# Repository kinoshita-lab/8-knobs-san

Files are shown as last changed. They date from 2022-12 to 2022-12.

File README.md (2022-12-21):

# 8-knobs-san kit

[Document in Japanese](README_ja.md)
## PCB board with 8 Potentiometers

8-knobs-san is a handy PCB with 8 potentiometers and analog multiplexer.
You can connect another 8-knobs-san PCB with same GPIOs, by switching /Enable pin with builtin inverter.

## Kit contents

- Pre-assembled circuit board
- 1x7 pin socket

## How to assemble

Solder the included 1x7 pin socket into the following place below:
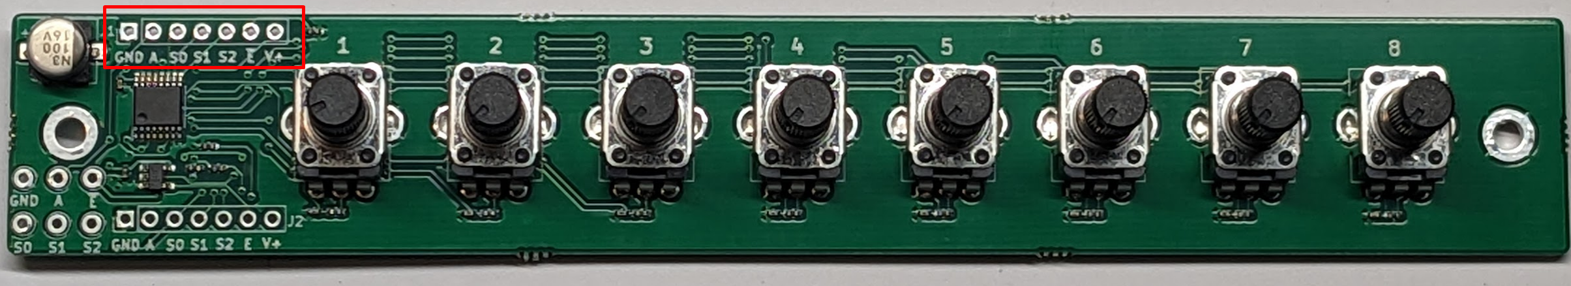
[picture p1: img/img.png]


## Sample program

Please refer to the software/exapmle <https://github.com/kinoshita-lab/8-knobs-san/tree/main/software/example>

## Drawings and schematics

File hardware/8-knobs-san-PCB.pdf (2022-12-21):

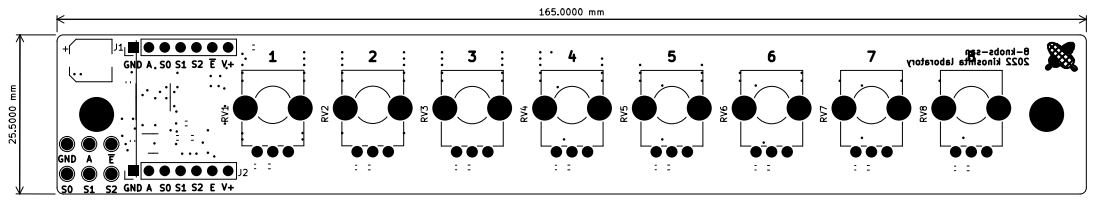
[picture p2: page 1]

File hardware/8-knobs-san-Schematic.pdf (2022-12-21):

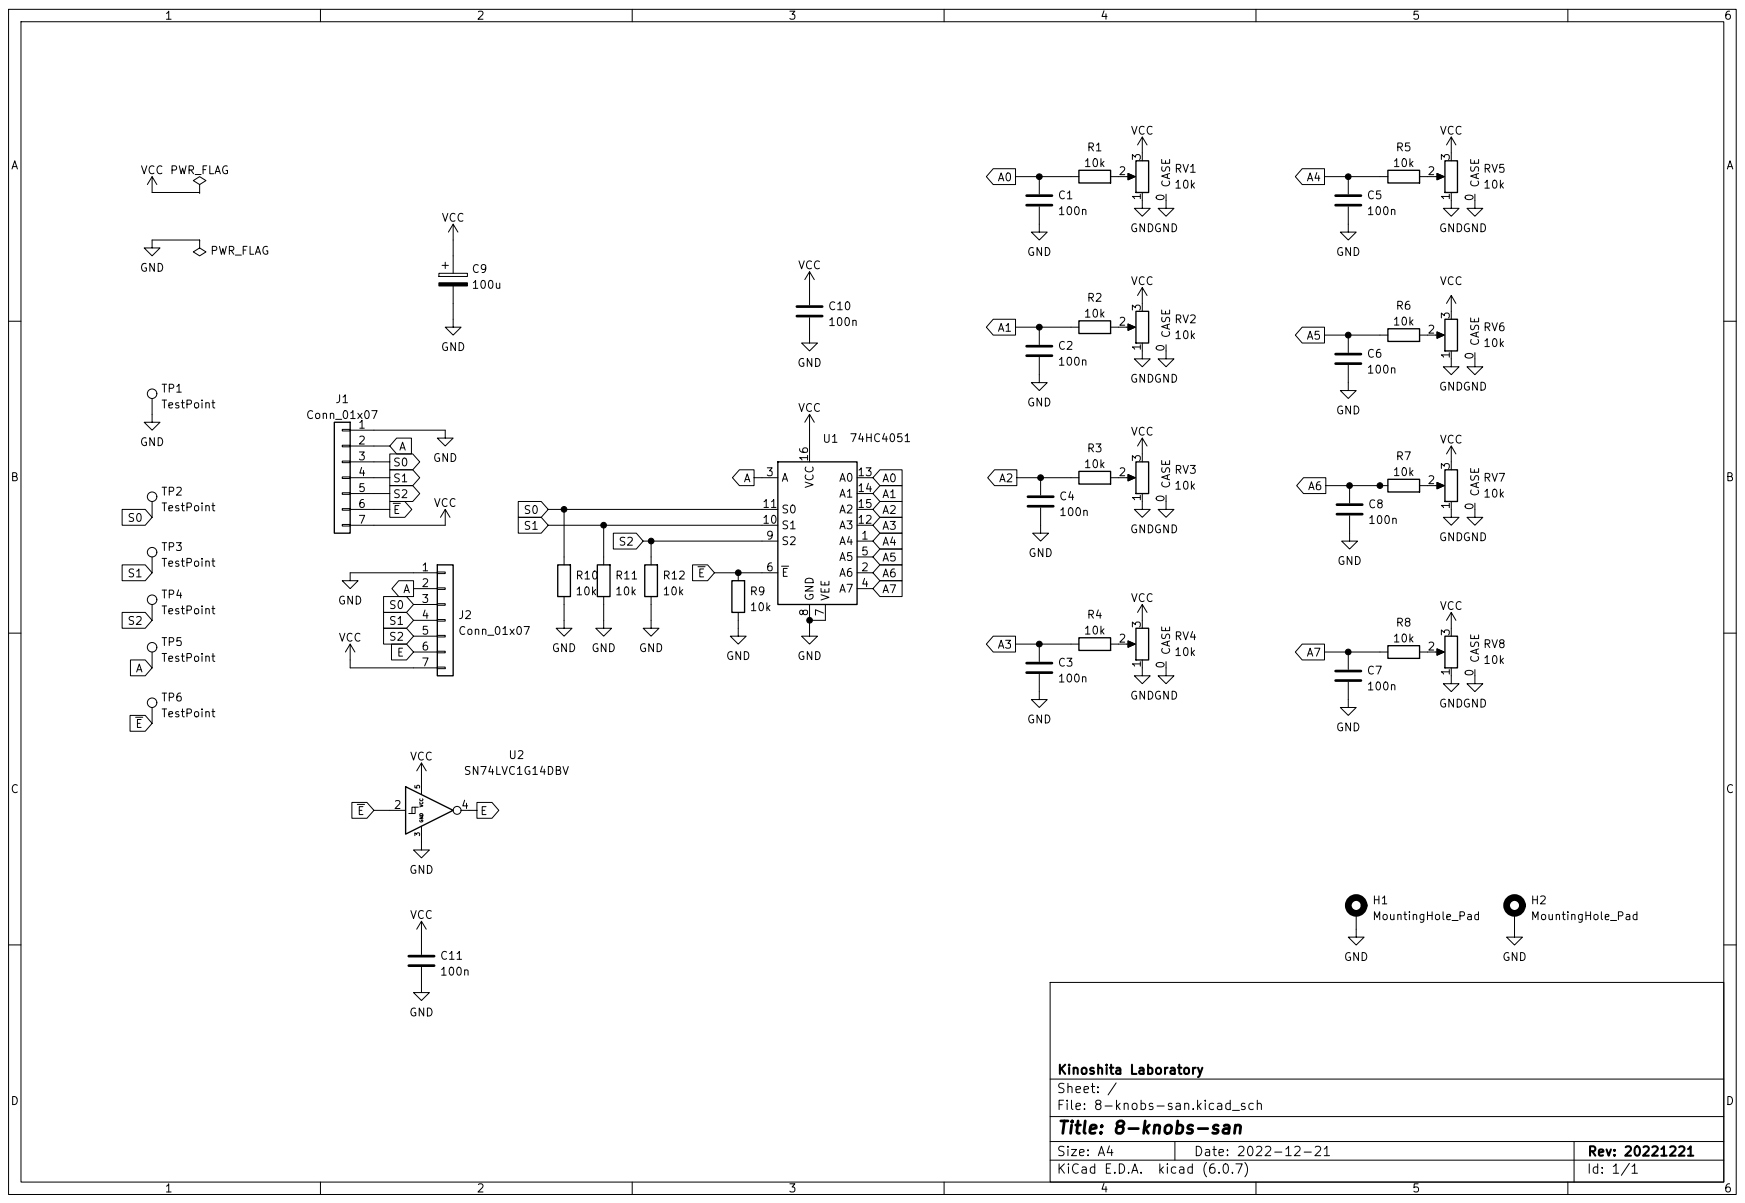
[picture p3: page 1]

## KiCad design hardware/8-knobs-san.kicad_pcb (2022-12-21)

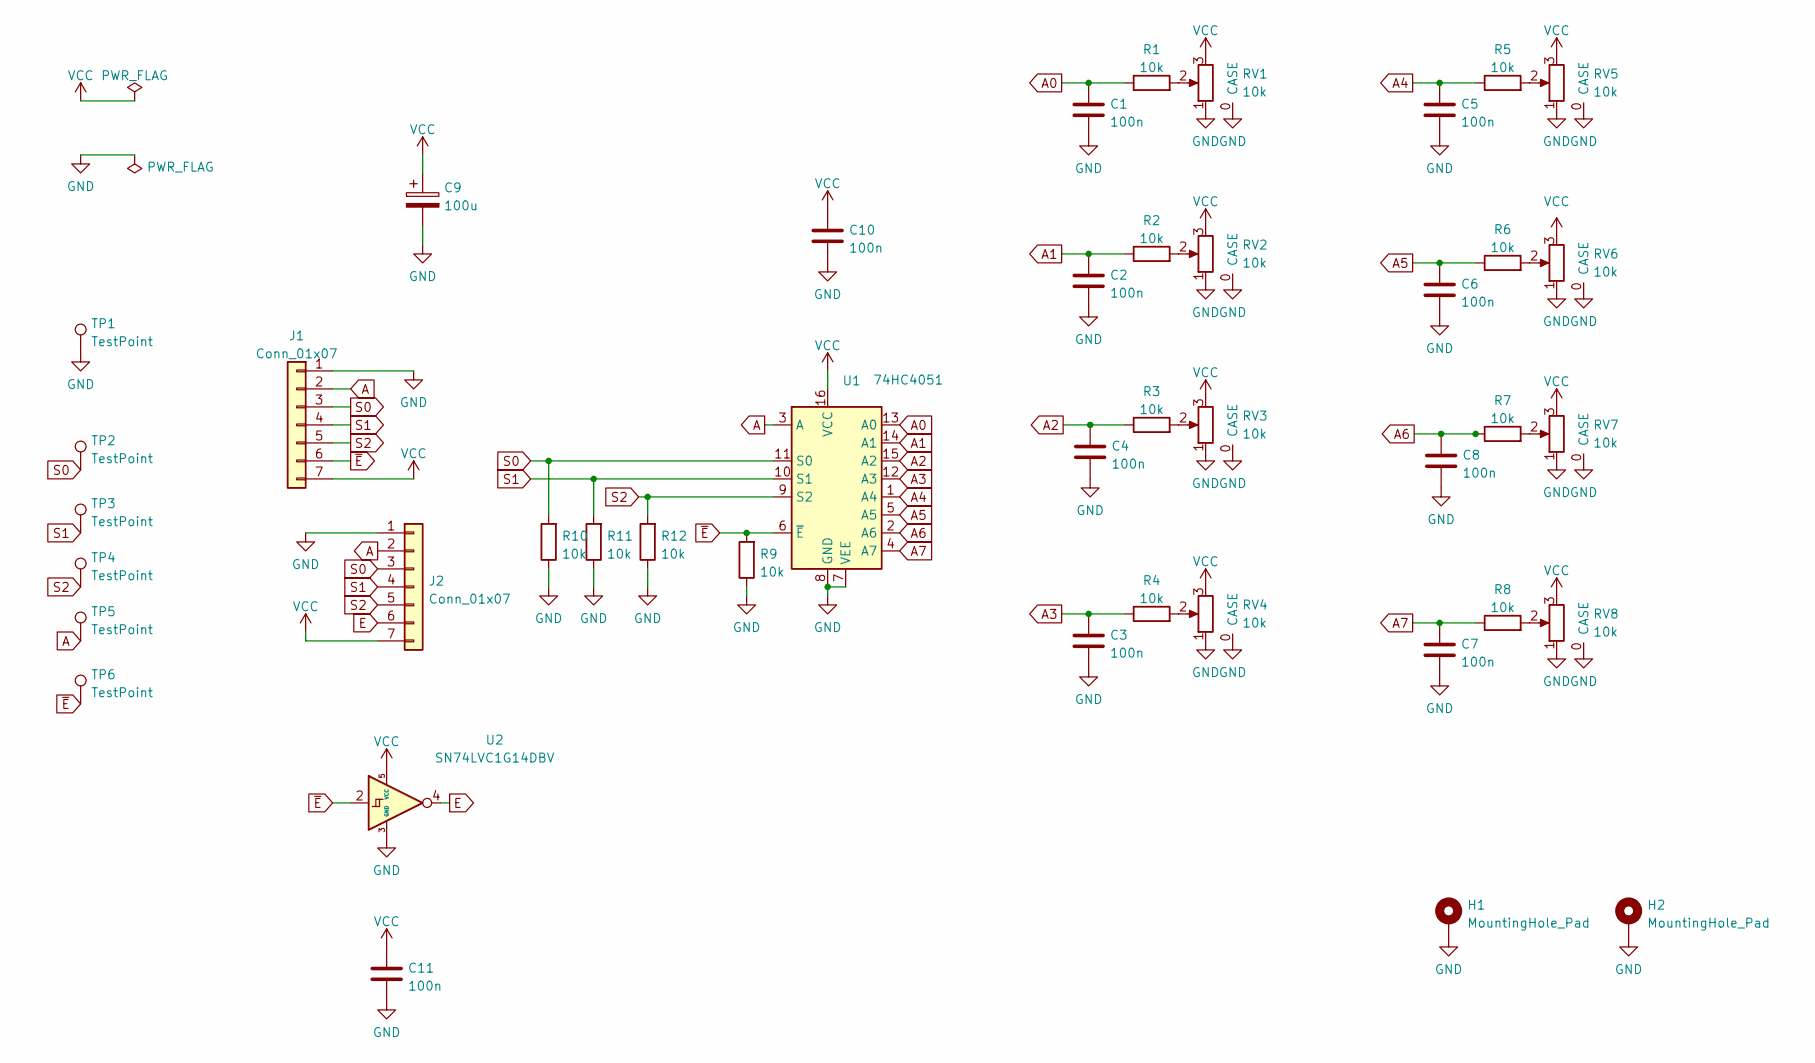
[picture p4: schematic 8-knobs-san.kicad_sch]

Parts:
C1, C2, C3, C4, C5, C6, C7, C8, C10, C11: 100n; C_0402_1005Metric; LCSC C1525
C9: 100u; CP_Elec_6.3x5.4_Nichicon; LCSC C111600
H1, H2: MountingHole_Pad; MountingHole_3.2mm_M3_DIN965_Pad
J1, J2: Conn_01x07; PinHeader_1x07_P2.54mm_Vertical
R1, R2, R3, R4, R5, R6, R7, R8, R9, R10, R11, R12: 10k; R_0402_1005Metric_Pad0.72x0.64mm_HandSolder; LCSC C25744
RV1, RV2, RV3, RV4, RV5, RV6, RV7, RV8: 10k; Potentiometer_Alps_RK09K_Horizontal_CORRECTED; LCSC C209779
TP1, TP2, TP3, TP4, TP5, TP6: TestPoint; TestPoint_THTPad_D2.0mm_Drill1.0mm
U1: 74HC4051; TSSOP-16_4.4x5mm_P0.65mm; LCSC C5645
U2: SN74LVC1G14DBV; SOT-23-5

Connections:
A: J1.2, J2.2, TP5.1, U1.3 (A)
A0: C1.1, R1.1, U1.13 (A0)
A1: C2.1, R2.1, U1.14 (A1)
A2: C4.1, R3.1, U1.15 (A2)
A3: C3.1, R4.1, U1.12 (A3)
A4: C5.1, R5.1, U1.1 (A4)
A5: C6.1, R6.1, U1.5 (A5)
A6: C8.1, R7.1, U1.2 (A6)
A7: C7.1, R8.1, U1.4 (A7)
E: J2.6, U2.4
GND: C1.2, C2.2, C3.2, C4.2, C5.2, C6.2, C7.2, C8.2, C9.2, C10.2, C11.2, H1.1, H2.1, J1.1, J2.1, R9.1, R10.1, R11.1, R12.1, RV1.0 (CASE), RV1.1, RV2.0 (CASE), RV2.1, RV3.0 (CASE), RV3.1, RV4.0 (CASE), RV4.1, RV5.0 (CASE), RV5.1, RV6.0 (CASE), RV6.1, RV7.0 (CASE), RV7.1, RV8.0 (CASE), RV8.1, TP1.1, U1.7 (VEE), U1.8 (GND), U2.3 (GND)
unnamed: R1.2, RV1.2
unnamed: R2.2, RV2.2
unnamed: R3.2, RV3.2
unnamed: R4.2, RV4.2
unnamed: R5.2, RV5.2
unnamed: R6.2, RV6.2
unnamed: R7.2, RV7.2
unnamed: R8.2, RV8.2
S0: J1.3, J2.3, R10.2, TP2.1, U1.11 (S0)
S1: J1.4, J2.4, R11.2, TP3.1, U1.10 (S1)
S2: J1.5, J2.5, R12.2, TP4.1, U1.9 (S2)
VCC: C9.1, C10.1, C11.1, J1.7, J2.7, RV1.3, RV2.3, RV3.3, RV4.3, RV5.3, RV6.3, RV7.3, RV8.3, U1.16 (VCC), U2.5 (VCC)
~E: J1.6, R9.2, TP6.1, U1.6 (~E), U2.2

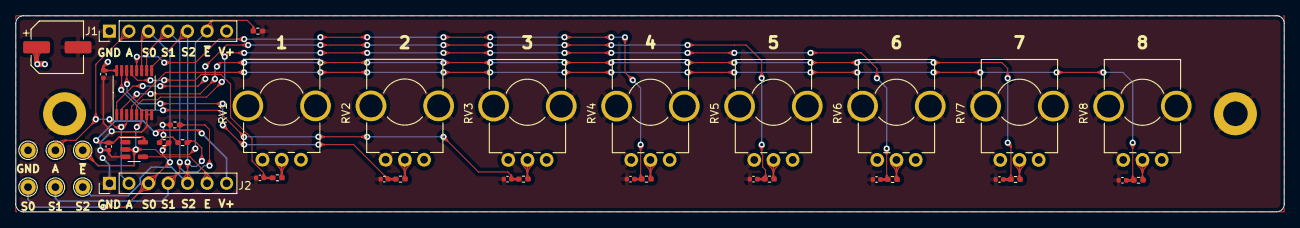
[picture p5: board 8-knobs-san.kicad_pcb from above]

Board: 2 copper layers, 165.0 x 25.5 mm, 43 parts (0 on the bottom side), 24 nets.

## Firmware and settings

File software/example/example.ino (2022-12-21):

#include <Arduino.h>

#include "AnalogMultiplexer74Hc4051.h"

enum
{
    kPinNEnable = 3,
    kPinS0      = 5,
    kPinS1      = 6,
    kPinS2      = 7,

    kAnalogIn = 0,
};

kinoshita_lab::AnalogMultiplexer74HC4051 multiplexer1(kPinNEnable, kPinS0, kPinS1, kPinS2, kAnalogIn);

float float_buf1[kinoshita_lab::AnalogMultiplexer74HC4051::kNumInputs] = {0.f};

int buf1[kinoshita_lab::AnalogMultiplexer74HC4051::kNumInputs] = {0};

void setup()
{
    Serial.begin(115200);

    // put your setup code here, to run once:

    multiplexer1.begin();

    for (auto i = 0; i < kinoshita_lab::AnalogMultiplexer74HC4051::kNumInputs; i++) {
        const auto value = multiplexer1.getValue(i) >> 1;
        buf1[i]          = value;
    }
}

void loop()
{
    // put your main code here, to run repeatedly:
    multiplexer1.update();

    for (int i = 0; i < kinoshita_lab::AnalogMultiplexer74HC4051::kNumInputs; i++) {
        const auto val   = multiplexer1.getFilteredValue(i) >> 1;
        const auto delta = abs(buf1[i] - val);
        if (delta) {
            buf1[i] = val;

            Serial.print("scan value[");
            Serial.print(i);
            Serial.print("] = ");
            Serial.println(val);
        }
    }
}

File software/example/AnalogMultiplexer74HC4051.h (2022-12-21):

/**
 * @file AnalogMultiplexer74Hc4051.h
 * @brief Simple library for 74HC4051 analog multiplexer.
 *
 * @author Kazuki Saita <saita@kinoshita-lab.com>
 *
 * Copyright (c) 2022 Kinoshita Lab. All rights reserved.
 *
 */

#pragma once
#ifndef ANALOGMULTIPLEXER74HC4051_H
#define ANALOGMULTIPLEXER74HC4051_H

#include <stdint.h>
#include <Arduino.h>

namespace kinoshita_lab
{
class AnalogMultiplexer74HC4051
{
public:
    enum
    {
        kNumInputs             = 8,
        kDefaultScanPeriodMsec = 1,
        kNumAvarage            = 1,
    };

    AnalogMultiplexer74HC4051(const int pin_nenable,
                              const int pin_s0,
                              const int pin_s1,
                              const int pin_s2,
                              const int analog_in,
                              const bool is_enable_active_low = true,
                              const int scan_period           = kDefaultScanPeriodMsec)
        : pins_(pin_nenable, pin_s0, pin_s1, pin_s2, analog_in),
          is_enable_active_low_(is_enable_active_low),
          scan_period_(scan_period)
    {
        pinMode(pins_.nenable, OUTPUT);
        pinMode(pins_.s0, OUTPUT);
        pinMode(pins_.s1, OUTPUT);
        pinMode(pins_.s2, OUTPUT);
    }

    float getAvaragedAnalogRead()
    {
        float result = 0.f;
        for (auto i = 0; i < kNumAvarage; i++) {
            result += analogRead(pins_.analog_in);
        }
        return result / kNumAvarage;
    }
    void begin()
    {
        selectInput(scan_index_);
        digitalWrite(pins_.nenable, is_enable_active_low_ ? LOW : HIGH);
        delay(1);

        for (auto i = 0; i < kNumInputs; i++) {
            selectInput(i);
            delay(1);
            scan_values_[i]     = getAvaragedAnalogRead();
            filters_[i].output_ = scan_values_[i];
        }
        last_scanned_millis_ = millis();
    }

    virtual ~AnalogMultiplexer74HC4051() = default;

    void update()
    {

        const unsigned long current_millis = millis();
        const unsigned long delta_millis   = abs(current_millis - last_scanned_millis_);

        if (delta_millis < scan_period_) {
            return;
        }
        last_scanned_millis_ = current_millis;
        const auto read      = getAvaragedAnalogRead();

        scan_values_[scan_index_] = read;
        filters_[scan_index_].update(read);

        // prepare for next
        scan_index_ = (scan_index_ + 1) % kNumInputs;
        selectInput(scan_index_);
        digitalWrite(pins_.nenable, is_enable_active_low_ ? LOW : HIGH);
    }

    void selectInput(const uint8_t index)
    {
        if (index >= kNumInputs) {
            return;
        }

        digitalWrite(pins_.s0, (index >> 0) & 0x01);
        digitalWrite(pins_.s1, (index >> 1) & 0x01);
        digitalWrite(pins_.s2, (index >> 2) & 0x01);
    }

    int getValue(const int index) const
    {
        return (int)scan_values_[index];
    }
    int getFilteredValue(const int index) const
    {
        return round(filters_[index].output_);
    }

protected:
    struct Pins
    {
        enum
        {
            kInvalidPinConfiguration = 0xff,
        };

        int nenable   = kInvalidPinConfiguration;
        int s0        = kInvalidPinConfiguration;
        int s1        = kInvalidPinConfiguration;
        int s2        = kInvalidPinConfiguration;
        int analog_in = kInvalidPinConfiguration;

        Pins() = default;
        Pins(const int pin_nenable,
             const int pin_s0,
             const int pin_s1,
             const int pin_s2,
             const int pin_analog_in)
            : nenable(pin_nenable), s0(pin_s0), s1(pin_s1), s2(pin_s2), analog_in(pin_analog_in)
        {
        }
    };
    class OnePoleIIR
    {
    public:
        static constexpr float kDefaultAlpha = 0.8f; ///< Tuned for  1ms, 1 average, 512 resolution

        OnePoleIIR() : alpha_(kDefaultAlpha), output_(0.0f) {}

        virtual ~OnePoleIIR() = default;

        void setLastValue(const float value)
        {
            output_ = value;
        }

        void update(const float input)
        {
            const auto output = alpha_ * input + (1.0f - alpha_) * output_;
            output_           = output;
        }
        float alpha_  = kDefaultAlpha;
        float output_ = 0.0f;
    };
    // configurations
    OnePoleIIR filters_[kNumInputs];

    Pins pins_;
    bool is_enable_active_low_ = true;
    unsigned long scan_period_ = kDefaultScanPeriodMsec;

    // state variables
    unsigned long last_scanned_millis_ = 0;
    int scan_index_                    = 0;
    float scan_values_[kNumInputs]     = {0.f};

private:
    AnalogMultiplexer74HC4051() = default;
};
}

#endif // ANALOGMULTIPLEXER74HC4051_H
